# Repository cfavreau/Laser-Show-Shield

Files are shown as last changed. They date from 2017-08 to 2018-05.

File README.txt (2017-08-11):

Open Laser Show DAC
Arduino Laser Shield
By Christopher Favreau
cfavreau@fab-favreau.com
Last revised on August 17, 2011
Current Hardware Version: 3B
Project Web Sites:
http://www.fab-favreau.com/index.php/Main/OpenLaserShowDAC
https://github.com/cfavreau/Laser-Show-Shield

All included materials are copyright Christopher Favreau 2010 to 2017

This work is licensed under the Creative Commons Attribution 3.0 Unported License.

You are free to share and remix this work as long as you attribute the me the author
somewhere on/in your related work.

To view a copy of this license, visit http://creativecommons.org/licenses/by/3.0/

Description
--------------------------------------------------------------------------------

The Open Laser Show DAC is an Open Source Hardware/Software project.

It implements a Laser Show DAC (Digital to Analog Converter) that uses the ILDA standard laser projector
connector. The one exception that it uses singled ended color signals.

Specifications->
Scan Rates: 1 kpps to 30 kpps
XY Resolution:  12 Bits
Color Resolution:  3 bits (for a total of 512 colors)
Colors: Red, Green, Blue outputs
TTL Shutter Output
Built in test patterns accessible by button.

This board is built as an Arduino Shield.   It requires a Arduino 2009 (Duemilanove) or compatible Arduino
micro-controller board.   The important thing that is needed for compatibility is the FTDI USB to Serial
converter chip.  The newer UNO boards are not supported yet.   In order for the software/hardware to work
properly a jumper wire needs to be added between the CTS pin on the Arduino/FTDI chip and digital pin 8.  
This is used to control the stream of serial data being sent to the Arduino.  Some boards make this easy and
include a pad for the CTS pin (Arduino and Seeduino brands).   The Freeduino will work however it does not
break out a pad for the CTS pin (this makes it a bit more difficult to modify).

------------------------------------------------------------------------------------------------------------

Included in this project:

OLSDTest
--------------------------------------------------------------------------------
This program is written in Microsoft Visual C++ using MFC (Visual Studio 2005).
Use this program to test the OLSD hardware.  This software includes several built
in test patterns inlcuding the ILDA12k, ILDA30k, Quadrature, Laser Media, and a
few other test frames that I devised.

OLSD DLL
--------------------------------------------------------------------------------
This is a DLL library that uses the Open Laser Show Controller interface.   It can be used
by other applications to interface with the OLSD hardware in a standard way.   This DLL project
is written in Microsoft Visual C++ (using Visual Studio 2005).

The source code for the DLL test application is included as well.

OLSD Firmware
--------------------------------------------------------------------------------
This is the Arduino firmware.  It was tested using Arduino Duemilanove
with ATMega328 (http://www.arduino.cc/en/Main/ArduinoBoardDuemilanove)

It will fit in a smaller amount of flash however you may need to remove some
of the built in test frames.

This firmware supports point output rates up to 30kpps.  It also has
built in test patterns.  These are activated by pressed the button near the ILDA
connector.

OLSD Laser Shield Hardware
--------------------------------------------------------------------------------
Schematic, Board Layout, Gerbers, and Bill Of Materials (with Digi-Key stock numbers).
The schematic and board were done in the free version of Eagle CAD.  A PDF version
of the schematic has been included.  All parts except for PCB and Arduino can be
purchased from Digi-Key using the included Digi-Key part numbers.

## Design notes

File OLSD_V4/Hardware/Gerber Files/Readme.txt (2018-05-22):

Gerber Files produced by Eagle Lite V5.11
Using the CAM file:  http://www.sparkfun.com/tutorial/BeginningEmbedded/9-EaglePCBs/sfe-gerb274x.cam
Files are in the Gerber RS274X format

* Top and bottom copper (.GTL, .GBL)
* Top and bottom solder mask (.GTS, .GBS)
* Top and bottom silkscreen (.GTO, .GBO)
* Drill file, 2.4 leading (.TXT)

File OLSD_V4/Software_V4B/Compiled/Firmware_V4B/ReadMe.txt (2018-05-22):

Please edit the PROGRAM.BAT file to use the COM# that your Arduino is on.

To find out please go to the Ports in the Device Manager.

avrdude.exe -V -F -C avrdude.conf -p m328p -c stk500v1 -P COM6 -b 57600 -U flash:w:olsd.hex:a

The above line is set for COM6.   Your COM# may vary.  Replace the "6" with your own number.
Then run the PROGRAM.BAT file by double clicking on it.   This will program the Arduino with 
the new firmware.

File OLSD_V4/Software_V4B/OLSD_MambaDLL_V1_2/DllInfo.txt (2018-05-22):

Drivers are simply Windows DLLs. If you want to write your own driver, you will have to
implement and export the following functions (Delphi syntax):

=================================================================================================================
function MLRegisterDriver(b: PChar): word stdcall;

This function has to copy the characters MLDevice into the buffer b. This is to make sure the
DLL is a valid driver. The function can return a number, which will then be passed to as
parameter h in the functions below (in case the hardware driver supports multiple clients, and
has to keep track of them).

=================================================================================================================
function MLDevicePresent: boolean; stdcall;

This function should return true if the device is present (or if there is no way to determine it).

=================================================================================================================
function MLKind: word; stdcall;

Returns 1 for a frame oriented device, 2 for a point oriented device, 4 for an animation
oriented device. (For the different devices see MLDraw.) If the function is not present a frame
oriented device will be assumed.
Mamba calls these functions on program start, so it can list all output devices that are
available.
The following functions are used to do output to the device. The parameter h is the above
mentioned return value from MLRegisterDriver, c is the channel number (in case the
hardware can support multiple output channels, mamba always uses channel 0).

=================================================================================================================
function MLGetName(n: pchar): boolean; stdcall;

When called the driver should copy a name (20 chars max) to n

=================================================================================================================
function MLInitDevice(h: word): boolean; stdcall;

Called once when the driver is selected.

=================================================================================================================
function MLInitShow(h, c: word): boolean; stdcall;

Called immediately before output starts

=================================================================================================================
function MLDraw(h, c: word; d: PChar; n: integer): boolean; stdcall;

For a frame oriented device (Riya PCI Pro for example) this function is called for each frame.

D is a pointer to an array with n points
Point= packed record
   x,y,z: word;
   r,g,b: byte;
   reserved1, reserved2, reserved3: byte;
   intensity, reserved4, repeatpoint: byte;
end;

if repeatpoint is greater than 0 it should be displayed 1+repeatpoint times.

For a point oriented device (MediaLas PCI 12 for example) this function is called once for
each point (same data format).

For animation oriented devices (MediaLas HotBoard for example) there will be a call to
MLInitShow, followed by calls to MLDraw for each frame, after the show is through
MLHaltShow will be called, and the data can be sent to the device.

=================================================================================================================
function MLHaltShow(h, c: word): boolean; stdcall;

Called when output stops.

=================================================================================================================
function MLHalt: boolean; stdcall;

Called when the driver is unloaded

=================================================================================================================
function MLParams(h: word; c: word; p: PChar): boolean; stdcall;

p is a pointer to a Params structure
Params= packed record
size: word;
pointrate: longint;
invertblanking: boolean;
end;

size is the size in bytes of the complete structure (right now values of 6 or 7 are used, please
make sure you driver checks for this parameters). For a frame oriented driver this function is
used to set the scanrate in points per second. If invertblanking is set, the driver should invert
all intensity values (if possible). The driver should use safe default values.

=================================================================================================================
Using a driver with your own software

If you plan to use a MediaLas driver with your own software you should at least call the
following functions:

MLDevicePresent (on startup)
MLInitDevice (before first output)
MLInitShow (before output starts)
MLHaltShow (to end output)
MLHalt (before closing program)

It is highly recommended to call MLKind (if present) to check whether the device is point,
frame, or animation oriented.

When calling MLName please make sure the buffer you pass is at least 21 bytes long. When
calling MLParams, set the size parameter correctly.

A simple example driver and program (in Delphi) is available, please contact MediaLas
technical support.

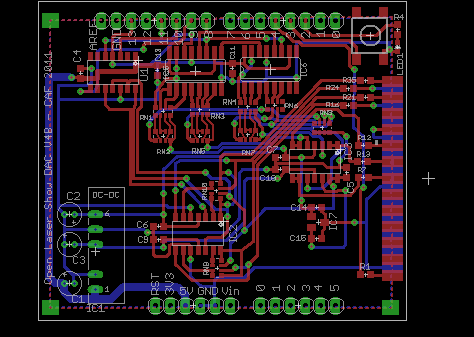
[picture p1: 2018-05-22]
OLSD_V4/Hardware/OLSD_V4B_Board.png

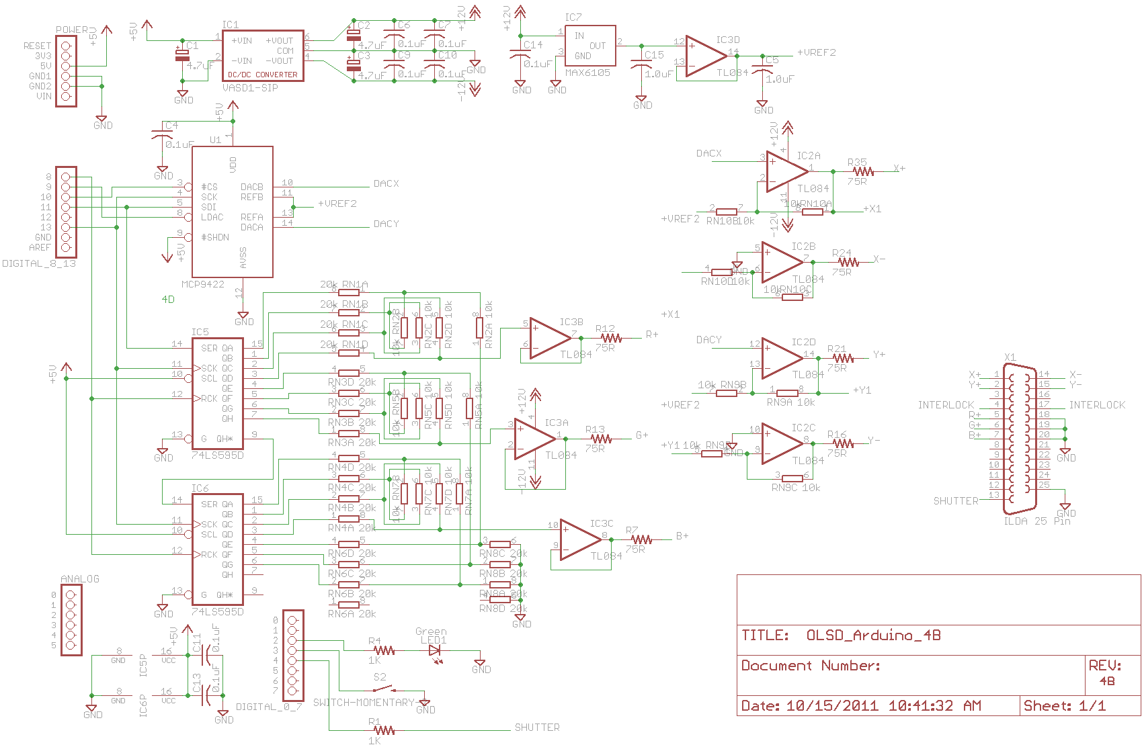
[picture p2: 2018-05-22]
OLSD_V4/Hardware/OLSD_V4B_Schematic.png

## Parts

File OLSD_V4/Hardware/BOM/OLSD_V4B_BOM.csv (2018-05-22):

Quantity | Name | Value | Digi-Key | Description | Parts | Cost Per Unit | Total Cost
2 | Resistor 0603 | 1K | P1.0KGCT-ND | 1k 1/10W 0603 Digikey 5% | R1, R4 | $0.02 | $0.04
7 | Resistor 0603 | 75R | P75GCT-ND | 75R 1/10W 0603 Digikey 5% | R7,R12,R13,R16,R21,R24,R35 | $0.02 | $0.14
2 | 10kx4 Resistor Array | CRA06E08310K0FTA | CRA6E810.0KACT-ND | RES ARRAY 10K OHM 4 RES 1206 1% (0603x4) | RN9, RN10 | $0.19 | $0.38
3 | 10kx4 Resistor Array | YC164-JR-0710KL | YC164J-10KTR-ND | RES ARRAY 10K OHM 8TRM 4 RES SMD 5%(0603 x 4) | RN2, RN5, RN7 | $0.04 | $0.12
5 | 20kx4 Resistor Array | YC164-JR-0720KL | YC164J-20KCT-ND | RES ARRAY 20K OHM 8TRM 4 RES SMD 5% (0603 x 4) | RN1, RN3, RN4, RN6, RN8 | $0.04 | $0.20
2 | 1.0 uF Capacitor 0603 | 1.0uF | 445-1327-1-ND | 1.0uF 16V 0603 package | C5, C15 | $0.17 | $0.34
3 | Capacitor Leaded | 4.7uF | ECE-A1EKA4R7 | 4.7 uF Electrolytic Capacitor 25V 20% | C1, C2, C3 | $0.23 | $0.69
8 | Capacitor 0603 | 0.1uF | 445-1326-1-ND | Bypass CAPs -> 0.1uF 16V 0603 package | C6, C7, C9, C10, C11, C13, C14, C15 | $0.07 | $0.56
1 | Male Header | 1x36 0.1" | WM6536-ND | Shield Header - 1 x 36 Male Header Gold Plated .24" mating length | U$1, U$2, U$3, U$4 | $1.50 | $1.50
1 | DB25 Female ILDA Conn | DB25 | L77SDB25S | CONN D-SUB RCPT 25POS GOLD FLASH | X1 | $1.41 | $1.41
1 | 12 Bit SPI DAC | MCP4922 | MCP4922T-E/SLCT-ND | 12 Bit Dual DAC Microchip - SPI - SOIC | U1 | $3.11 | $3.11
1 | SPST Push Button Switch | SPST | 450-1759-1-ND | SWITCH TACT MINI 6X6MM SMD | S2 | $0.24 | $0.24
2 | Quad Opamp | TL084CD | 497-3033-5-ND | Quad JFET OpAmp - SOIC Package | IC2, IC3 | $0.70 | $1.40
1 | 5V to +-12V DC to DC | RB-0512D | 945-1105-ND | CONV DC/DC 1W DL +/-12V OUT SIP | IC1 | $6.82 | $6.82
1 | Green LED 0603 |  | 475-2709-1-ND | LED SMARTLED GREEN 570NM 0603 @ 2mA = 2 mcd w/ 1.7V Forward Voltage | LED1 | $0.16 | $0.16
2 | 595 Shift Register | 74VHC595M | 74VHC595M-ND | IC REGISTER SHIFT 8BIT 16-SOIC | IC5, IC6 | $0.43 | $0.86
1 | 5.0V Voltage Reference | MAX6105EUR+T | MAX6105EUR+TCT-ND | Maxim 5V Precision Voltage Reference | IC7 | $0.78 | $0.78
Total Cost: |  | $18.75 |  |  | Total Cost: |  | $18.75
1 | 5V to +-12V DC to DC | VASD1-S5-D12-SIP | 102-1340-ND | CONVERTER DC/DC +/-12V OUT +5V IN 1W | IC1 | $5.58 | $5.58

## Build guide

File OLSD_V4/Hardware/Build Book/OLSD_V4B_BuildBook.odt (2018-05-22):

IC1 - 5V to +-12V DC to DC – 945-1105-ND – RB-0512D

Notes: None

C1, C2, C3 - 4.7 uF Electrolytic Capacitor 25V 20% – ECE-A1EKA4R7 – 4.7uF

Notes: Please pay attention to the polarity. All of the capacitors are not polarized in the same orientation on the board.

IC7 - 5.0V Voltage Reference – MAX6105EUR+TCT-ND – MAX6105EUR+T

Notes: None.

C5, C15 - 1.0 uF Capacitor 0603 – 445-1327-1-ND – 1.0 uF 0603

Notes: None.

LED1 - Green LED 0603 – 475-2709-1-ND

Notes: The orientation of the LED is important. Please orient the LED according to this drawing.

R1, R4 – 1k Resistor 0603 – P1.0KGCT-ND – 1k 0603

Notes: None.

S2 - SWITCH TACT MINI 6X6MM SMD – 450-1759-1-ND

Notes: None.

C6, C7, C9, C10, C11, C13, C14, C15- 0.1 uF Capacitor 0603 – 445-1326-1-ND – 0.1 uF 0603

Notes: None.

R7,R12,R13,R16,R21,R24,R35- 75R Resistor 0603 – P75GCT-ND

Notes: None.

RN9, RN10- RES ARRAY 10K OHM 4 RES 1206 1% (0603x4) – CRA6E810.0KACT-ND - CRA06E08310K0FTA

Notes: Please note that these are 1% resistor packs where as the ones used in the R2R color DACs are 5%. Do not mix them up.

RN2, RN5, RN7 - RES ARRAY 10K OHM 8TRM 4 RES SMD 5%(0603 x 4) – YC164J-10KTR-ND – YC164-JR-0710KL

Notes: None.

RN1, RN3, RN4, RN6, RN8 - RES ARRAY 20K OHM 8TRM 4 RES SMD 5% (0603 x 4) – YC164J-20KCT-ND - YC164-JR-0720KL

Notes: None.

U1 - 12 Bit Dual DAC Microchip - SPI - SOIC – MCP4922T-E/SLCT-ND – MCP4922

Notes: The dot on the board drawing represents pin 1 on the DAC.

IC5, IC6 - IC REGISTER SHIFT 8BIT 16-SOIC - 74VHC595M-ND – 74VHC595M

Notes: The dot on the board drawing represents pin 1 on the chip.

IC2, IC3 - Quad JFET OpAmp - SOIC Package – 497-3033-5-ND – TL084CD

Notes: The dot on the board drawing represents pin 1 on the chip. Pin 1 on the chip is represented by a flat edge and not by a dot.

U$1, U$2, U$3, U$4 - Shield Header - 1 x 36 Male Header Gold Plated .24" mating length – WM6536-ND

Notes: The single 36 pin header will have to be split into 2 x 8 sections and 2 x 6 sections. There will be a left over piece.

X1 – DB25 Female Solder Cup – L77SDB25S

Notes: The cups on the connector may have to be widened slightly using a screw driver or a scrap piece of circuit board. This connector is pressed on and then soldered. The top of the board is the top of the connector with pin 1.

OLSD V4B – Build Book – October 19, 2011

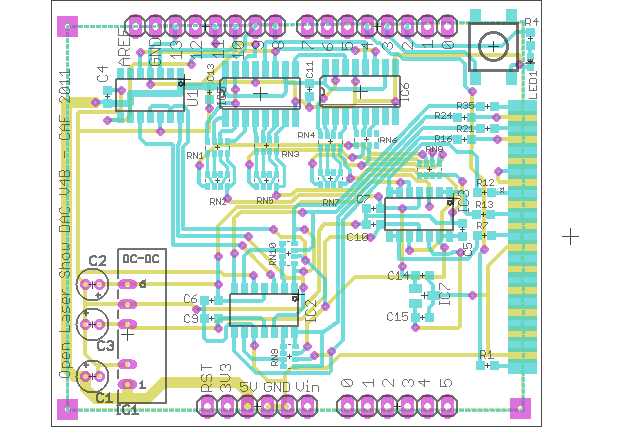
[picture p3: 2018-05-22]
OLSD_V4/Hardware/Build Book/OLSD_V4B_BoardBasePicture.png

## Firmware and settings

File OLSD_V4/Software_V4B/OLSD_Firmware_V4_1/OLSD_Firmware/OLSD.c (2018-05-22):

// Open Laser Show DAC V4B
// By Christopher Favreau
#warning PUT LICENSE HERE!!!
#include <avr/interrupt.h>
#include <avr/io.h>
#include "standard.h"
#include "usart.h"
#include "spi.h"
#include "timer.h"
#include "switch.h"
#include "test_frames.h"

// Port Map
// Jmp   Arduino Pin	AVR Pin		Direction	OLSD Func
//-----------------------------------------------------------------------------
// J1		Digital 0	PD0			Input		Serial RXD (on Arduino)
// J1		Digital 1	PD1			Output		Serial TXD (on Arduino)
// J1		Digital 2	PD2			Output		Status LED (1 == ON)
// J1		Digital 3	PD3(INT1)	Input		User Switch (0 == Pressed)
// J1		Digital 4	PD4			Output		ILDA Shutter
// J1		Digital 7	PD7			Output		#CTS (needs jumper #CTS->FTDI)
// J2		Digital	8	PB0			Output		Latch Color Regs (1 == Latch)
// J2		Digital 9	PB1			Output		#LDAC on uChip DAC
// J2		Digital 10	PB2(SS)		Output		#CS on uChip DAC
// J2		Digital 11	PB3(MOSI)	Output		MOSI (SPI Data Out)
// J2		Digital 13	PB5(SCK)	Output		SCK (SPI Serial Clock)

// Store the Identifier in FLASH
unsigned char OLSD_IDENTIFIER_STRING[] PROGMEM = "OLSD4.1.0\0";

// Status LED Variables
unsigned int status_counter = 0;

// Output Variables
BYTE command = 0;
BYTE x = 0;
BYTE y = 0;
BYTE red = 0;
BYTE green = 0;
BYTE blue = 0;
BYTE fifthbits = 0;

// Laser Packet
BYTE dcommand = 0;
BYTE dx = 0;
BYTE dy = 0;
BYTE dxy = 0;
BYTE drg = 0;
BYTE dbi = 0;

WORD spi_word = 0;

// Pointer to the reset vector for the firmware
void (*reset)( void ) = 0x0000;
void blank_and_center(void);

// ----------------------------------------------------------------------

BOOL output_monochrome_pattern = FALSE;
BOOL output_swap_xy = FALSE;

void output_pattern(BYTE *pStream, unsigned int length)
{
	unsigned int i = 0;

	while (i < length)
	{
		// Read a command
		command = pgm_read_byte(&pStream[i++]);

		// This being a test frame
		// We should... have a point output command
		if ((command != 0x20) && (command != 0x21))
		{
			// hmmm... we had some other command
			// Just get the next byte in the streams
			continue;
		}

		// Read the X and Y coordinates from the stream
		dx = pgm_read_byte(&pStream[i++]);
		dy = pgm_read_byte(&pStream[i++]);
		dxy = pgm_read_byte(&pStream[i++]);
		
		// Check to see if the colors stay the same
		// If they do stay the same then don't load the color bytes
		if (command != 0x21)
		{
			// Read the color bytes
			drg = pgm_read_byte(&pStream[i++]);
			dbi = pgm_read_byte(&pStream[i++]);
		}
		
		// Output our point
		// Now output the actual point
		
		// Decode into 4 bit RGBI
		red = (drg >> 4);
		green = (drg & 0x0F);
		blue = (dbi >> 4);
		
		// Check the monochrome flag
		if (output_monochrome_pattern)
		{
			// Make all the colors the same brightness
			register unsigned char color = red;
			if (green > color) color = green;
			if (blue > color) color = blue;
			red = color;
			green = color;
			blue = color;
		}

		// Do the fifth bit for the color
		fifthbits = 0;
		if (red) fifthbits |= 0x10;
		if (green) fifthbits |= 0x20;
		if (blue) fifthbits |= 0x40;

		// Check to see if it is time to output a point yet?
		while (!output_flag) asm("nop");
		// Reset our output flag/counter
		output_flag = 0;

		// Pull up the latch lines on the DAC and colors before we
		// go and send more data down the SPI bus
		// LDAC
		portb.bit1 = 1;
		// Color Latches
		portb.bit0 = 0;

		// Load DAC A
		// X X X PowerMode Load Output AddrB AddrA 
		// pull down chip select!
		if (!output_swap_xy)
			spi_word = 0b0111000000000000 | (dy << 4) | ((dxy & 0xF0) >> 4);
		else
			spi_word = 0b0111000000000000 |(dx << 4) | (dxy & 0x0F);
		portb.bit2 = 0;
		SPDR = spi_word >> 8;
		while (!(SPSR & (1 << SPIF)));
		SPDR = spi_word & 0x00FF;
		while (!(SPSR & (1 << SPIF)));
		// pull up chip select!
		portb.bit2 = 1;
		asm("nop");
		
		// NOP NOP NOP NOP!??? how many?
		// Load DAC B and update the output (assign a 0 to output)
		// pull down chip select!
		if (!output_swap_xy)
			spi_word = 0b1111000000000000 | (dx << 4) | (dxy & 0x0F);
		else
			spi_word = 0b1111000000000000 | (dy << 4) | ((dxy & 0xF0) >> 4);
		portb.bit2 = 0;
		SPDR = spi_word >> 8;
		while (!(SPSR & (1 << SPIF)));
		SPDR = spi_word & 0x00FF;
		while (!(SPSR & (1 << SPIF)));
		// Pull up chip select!
		portb.bit2 = 1;

		// Colors
		// *** REMEMBER that a shift register passes the 1st 8 bits
		// on to the 2nd shift register so we do the BLUE first!
		// B goes first
		SPDR = fifthbits | blue;
		while (!(SPSR & (1 << SPIF)));
		
		// RG go second
		SPDR = (green << 4) | red;
		while (!(SPSR & (1 << SPIF)));
		
		// Now latch the Colors and the DAC
		portb.bit0 = 1;

		// Pull the LDAC line LOW to load the DAC's values
		portb.bit1 = 0;

		// and set the shutter to OFF since it might be ON
		portd.bit4 = 0;

		// Do the Status LED
		status_counter++;
		if (status_counter < 500)
		{
			// Reset the LED to flip
			portd.bit2 = 1;
		}
		else
		{
			portd.bit2 = 0;
		}
		if (status_counter > 1000) status_counter = 0;
	}
}

void output_test_pattern(void)
{
	// Clear the button press
	switch_pressed = 0;

	// Reset the output monochrome flag
	output_monochrome_pattern = FALSE;

	// The first button press starts the ILDA 12k Test Pattern
	// Then:  Square Wave, Laser Media, New Test Pattern
	// This Round: 12 kpps
	// Next Round: 30 kpps

	while (1)
	{
		switch ((switch_pressed % 13) + 1)
		{
		case (1):
			set_timer_pps(12000);
			output_pattern(ILDA12K_IMAGE, ILDA12K_POINT_COUNT);
			break;
		case (2):
			set_timer_pps(12000);
			output_pattern(SQUARE_IMAGE, SQUARE_POINT_COUNT);
			break;
		case (3):
			set_timer_pps(12000);
			output_pattern(LASERMEDIA_IMAGE, LASERMEDIA_POINT_COUNT);
			break;
		case (4):
			set_timer_pps(12000);
			output_pattern(NEWTEST_IMAGE, NEWTEST_POINT_COUNT);
			break;
		case (5):
			set_timer_pps(12000);
			output_swap_xy = TRUE;
			output_pattern(NEWTEST_IMAGE, NEWTEST_POINT_COUNT);
			output_swap_xy = FALSE;
			break;
		case (6):
			blank_and_center();
			// We are already blanked... just wait for the switch
			wait_for_switch();
			break;
		case (7):
			set_timer_pps(30000);
			output_pattern(ILDA12K_IMAGE, ILDA12K_POINT_COUNT);
			break;
		case (8):
			set_timer_pps(30000);
			output_pattern(SQUARE_IMAGE, SQUARE_POINT_COUNT);
			break;
		case (9):
			set_timer_pps(30000);
			output_pattern(LASERMEDIA_IMAGE, LASERMEDIA_POINT_COUNT);
			break;
		case (10):
			set_timer_pps(30000);
			output_pattern(NEWTEST_IMAGE, NEWTEST_POINT_COUNT);
			break;
		case (11):
			set_timer_pps(30000);
			output_swap_xy = TRUE;
			output_pattern(NEWTEST_IMAGE, NEWTEST_POINT_COUNT);
			output_swap_xy = FALSE;
			break;
		case (12):
			blank_and_center();
			// Toggle the monochrome flag
			output_monochrome_pattern = !output_monochrome_pattern;
			// It is important to block so we don't toggle this flag
			// randomly ... wait for the switch again
			wait_for_switch();
			break;
		}
	}
}

inline void PrintIdentifier(void)
{
	// Get the OLSD Identifier from Flash instead of RAM
	// so we don't use up valuable RAM
	unsigned char i = 0;
	unsigned char byte = pgm_read_byte(&OLSD_IDENTIFIER_STRING[i]);
	// Loop until we run into the NULL terminator
	while (byte)
	{
		USART_Write(byte);
		byte = pgm_read_byte(&OLSD_IDENTIFIER_STRING[i++]);
	}
}

void blank_and_center(void)
{
	// Define a center
	#define CENTER_X 2047
	#define CENTER_Y 2047

	// Pull up the latch lines on the DAC and colors before we
	// go and send more data down the SPI bus
	// LDAC
	portb.bit1 = 1;
	// Color Latches
	portb.bit0 = 0;

	// Load DAC A
	// X X X PowerMode Load Output AddrB AddrA 
	// pull down chip select!
	spi_word = 0b0111000000000000 | CENTER_X;
	portb.bit2 = 0;
	SPDR = spi_word >> 8;
	while (!(SPSR & (1 << SPIF)));
	SPDR = spi_word & 0x00FF;
	while (!(SPSR & (1 << SPIF)));
	// pull up chip select!
	portb.bit2 = 1;
	asm("nop");
	
	// NOP NOP NOP NOP!??? how many?
	// Load DAC B and update the output (assign a 0 to output)
	// pull down chip select!
	spi_word = 0b1111000000000000 | CENTER_Y;
	portb.bit2 = 0;
	SPDR = spi_word >> 8;
	while (!(SPSR & (1 << SPIF)));
	SPDR = spi_word & 0x00FF;
	while (!(SPSR & (1 << SPIF)));
	// Pull up chip select!
	portb.bit2 = 1;

	// Colors
	// RG go first
	SPDR = 0;
	while (!(SPSR & (1 << SPIF)));
	
	// B (and the 5th bits) go next
	SPDR = 0;
	while (!(SPSR & (1 << SPIF)));
	
	// Now latch the Colors and the DAC
	portb.bit0 = 1;

	// Pull the LDAC line LOW to load the DAC's values
	portb.bit1 = 0;

	// and set the shutter to closed!!!
	portd.bit4 = 1;

	// Wait a few cycles before setting the latch lines up again
	asm("nop");
	asm("nop");
	asm("nop");
	asm("nop");

	// Pull up the latch lines on the DAC and colors before we
	// go and send more data down the SPI bus
	// LDAC
	portb.bit1 = 1;
	// Color Latches
	portb.bit0 = 0;
}

// DEBUG
unsigned char cx = 0;
unsigned char cy = 0;

int main(void)
{
	// Initialize our IO Ports
	
	// Port D - Serial + Status LED + User Switch + Shutter + CTS
	DDRD = 0b10010100;
	//PORTD = 0b00000011;
	// Pull up the user switch line
	ddrd.bit3 = 0;
	portd.bit3 = 1;

	/*
	// Test LED and Switch CODE
	while (1)
	{
		portd.bit2 = !pind.bit3;
	}
	*/

	// Initialize our SPI port to output to our DAC
	ddrb.bit2 = 1;
	portb.bit2 = 1;
	SPI_Init();

	// LDAC - disable
	ddrb.bit1 = 1;
	portb.bit1 = 1;

	// CTS Pin
	ddrb.bit0 = 1;
	portb.bit0 = 0;

	// Status LED
	ddrc.bit4 = 1;
	// Turn the LED ON
	portd.bit2 = 1;

	// Initialize our USART at 2 Mbps
	USART_Init();

	// Initialize the output point timer
	init_timer();

	// Blank and center
	blank_and_center();

	// Initialize the button input device
	init_switch();

	// Turn on interrupts
	sei();

	// Print Boot Message
	PrintIdentifier();

	CTS_ON;

	// DEBUG
	//output_test_pattern();
	//while (1) output_pattern(NEWTEST_IMAGE, NEWTEST_POINT_COUNT);

	// Loop forever
	while (1)
	{
		// Tell the USB chip we want to start getting data over our serial port
		CTS_ON;

		// DEBUG
		//switch_pressed = 1;
		
		// Read the command byte from the packet
		//READ(command);
		while (!(UCSR0A & (1 << RXC0)) && (switch_pressed == 0)); dcommand = UDR0;
		//while (!(UCSR0A & (1 << RXC0))); dcommand = UDR0;
		//READ(dcommand);

		///*
		// Before we read a command packet
		// We need to check to see if the button was pressed.
		// If the button was pressed then go into the Test Output Routine
		if (switch_pressed > 0)
		{
			// Jump to the test pattern routine
			output_test_pattern();
			// If we ever return...
			// Rejoin the loop after we are done with the test pattern
			continue;
		}
		//*/

		// Extract the command from the dcommand byte
		command = dcommand & 0xF0;

		// Check to see if we have a point output command
		// Command 0x20 -> Output Point
		if (command != 0x20)
		{
			// Check to see if it is a synchronization command
			if (command == 0xFF) continue;
			
			// Read the rest of the packet
			READ(dx);
			READ(dy);
			READ(dxy);
			READ(drg);

			// Check to see if it is a point output rate command
			if (command == 0x10)
			{
				// Set the point output rate
				// dx is the upper byte and dy is the lower byte
				// of the 16 bit unsigned pps rate
				set_timer_pps((dx << 8) + dy);
			}
			else
			// Check to see if it is a Reset command
			if (command == 0xF0)
			{
				// Reset the Firmware
				reset();
			}
			else
			// Check to see if it is Identify command
			if (command == 0xE0)
			{
				// Send the identifier string
				PrintIdentifier();
			}
			else
			{
				// What was that
				USART_Write('?');
			}

			// We aren't going to output a point
			continue;
		}

		// Command 0x20 - point output
		// Read the XY and colors
		READ(dx);
		READ(dy);
		READ(dxy);
		READ(drg);
		
		// Tell the USB chip we want to STOP getting data over our serial port
		CTS_OFF;
		
		// Output our point
		
		// Decode into 4 bit RGBI
		red = (drg >> 4);
		green = (drg & 0x0F);
		blue = (dcommand & 0x0F);
		
		// Fifth bits are the UPPER Nibble
		fifthbits = 0;
		if (red) fifthbits |= 0x10;
		if (green) fifthbits |= 0x20;
		if (blue) fifthbits |= 0x40;

		// Check to see if it is time to output a point yet?
		while (!output_flag) asm("nop");
		// Reset our output flag/counter
		output_flag = 0;

		// Pull up the latch lines on the DAC and colors before we
		// go and send more data down the SPI bus
		// LDAC
		portb.bit1 = 1;
		// Color Latches
		portb.bit0 = 0;

		// Load DAC A
		// X X X PowerMode Load Output AddrB AddrA 
		// pull down chip select!
		spi_word = 0b0111000000000000 | (dy << 4) | ((dxy & 0xF0) >> 4);
		portb.bit2 = 0;
		SPDR = spi_word >> 8;
		while (!(SPSR & (1 << SPIF)));
		SPDR = spi_word & 0x00FF;
		while (!(SPSR & (1 << SPIF)));
		// pull up chip select!
		portb.bit2 = 1;
		asm("nop");
		
		// NOP NOP NOP NOP!??? how many?
		// Load DAC B and update the output (assign a 0 to output)
		// pull down chip select!
		spi_word = 0b1111000000000000 | (dx << 4) | (dxy & 0x0F);
		portb.bit2 = 0;
		SPDR = spi_word >> 8;
		while (!(SPSR & (1 << SPIF)));
		SPDR = spi_word & 0x00FF;
		while (!(SPSR & (1 << SPIF)));
		// Pull up chip select!
		portb.bit2 = 1;

		// Colors
		// *** REMEMBER that a shift register passes the 1st 8 bits
		// on to the 2nd shift register so we do the BLUE first!
		// B goes first
		SPDR = fifthbits | blue;
		while (!(SPSR & (1 << SPIF)));

		// RG go second
		SPDR = (green << 4) | red;
		while (!(SPSR & (1 << SPIF)));
		
		// Now latch the Colors and the DAC
		portb.bit0 = 1;

		// Pull the LDAC line LOW to load the DAC's values
		portb.bit1 = 0;

		// and set the shutter to OFF since it might be ON
		portd.bit4 = 0;

		// Do the Status LED
		status_counter++;
		if (status_counter < 500)
		{
			// Reset the LED to flip
			portd.bit2 = 1;
		}
		else
		{
			portd.bit2 = 0;
		}
		if (status_counter > 1000) status_counter = 0;
	}

	return 1;
}

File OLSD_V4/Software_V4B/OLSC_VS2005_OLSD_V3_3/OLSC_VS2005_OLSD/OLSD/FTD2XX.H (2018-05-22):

/*++

Copyright (c) 2001-2004  Future Technology Devices International Ltd.

Module Name:

    ftd2xx.h

Abstract:

    Native USB device driver for FTDI FT8U232/245
    FTD2XX library definitions

Environment:

    kernel & user mode

Revision History:

    13/03/01    awm     Created.
	13/01/03	awm		Added device information support.
	19/03/03	awm		Added FT_W32_CancelIo.
	12/06/03	awm		Added FT_StopInTask and FT_RestartInTask.
	18/09/03	awm		Added FT_SetResetPipeRetryCount.
	10/10/03	awm		Added FT_ResetPort.
	23/01/04	awm		Added support for open-by-location.
	16/03/04	awm		Added support for FT2232C.
	23/09/04	awm		Added support for FT232R.

	
--*/

#include <windows.h>

#ifndef FTD2XX_H
#define FTD2XX_H

// The following ifdef block is the standard way of creating macros
// which make exporting from a DLL simpler.  All files within this DLL
// are compiled with the FTD2XX_EXPORTS symbol defined on the command line.
// This symbol should not be defined on any project that uses this DLL.
// This way any other project whose source files include this file see
// FTD2XX_API functions as being imported from a DLL, whereas this DLL
// sees symbols defined with this macro as being exported.

#ifdef FTD2XX_EXPORTS
#define FTD2XX_API __declspec(dllexport)
#else
#define FTD2XX_API __declspec(dllimport)
#endif


typedef PVOID	FT_HANDLE;
typedef ULONG	FT_STATUS;

//
// Device status
//
enum {
    FT_OK,
    FT_INVALID_HANDLE,
    FT_DEVICE_NOT_FOUND,
    FT_DEVICE_NOT_OPENED,
    FT_IO_ERROR,
    FT_INSUFFICIENT_RESOURCES,
    FT_INVALID_PARAMETER,
    FT_INVALID_BAUD_RATE,

    FT_DEVICE_NOT_OPENED_FOR_ERASE,
    FT_DEVICE_NOT_OPENED_FOR_WRITE,
    FT_FAILED_TO_WRITE_DEVICE,
    FT_EEPROM_READ_FAILED,
    FT_EEPROM_WRITE_FAILED,
    FT_EEPROM_ERASE_FAILED,
	FT_EEPROM_NOT_PRESENT,
	FT_EEPROM_NOT_PROGRAMMED,
	FT_INVALID_ARGS,
	FT_NOT_SUPPORTED,
	FT_OTHER_ERROR
};


#define FT_SUCCESS(status) ((status) == FT_OK)

//
// FT_OpenEx Flags
//

#define FT_OPEN_BY_SERIAL_NUMBER    1
#define FT_OPEN_BY_DESCRIPTION      2
#define FT_OPEN_BY_LOCATION			4

//
// FT_ListDevices Flags (used in conjunction with FT_OpenEx Flags
//

#define FT_LIST_NUMBER_ONLY			0x80000000
#define FT_LIST_BY_INDEX			0x40000000
#define FT_LIST_ALL					0x20000000

#define FT_LIST_MASK (FT_LIST_NUMBER_ONLY|FT_LIST_BY_INDEX|FT_LIST_ALL)

//
// Baud Rates
//

#define FT_BAUD_300			300
#define FT_BAUD_600			600
#define FT_BAUD_1200		1200
#define FT_BAUD_2400		2400
#define FT_BAUD_4800		4800
#define FT_BAUD_9600		9600
#define FT_BAUD_14400		14400
#define FT_BAUD_19200		19200
#define FT_BAUD_38400		38400
#define FT_BAUD_57600		57600
#define FT_BAUD_115200		115200
#define FT_BAUD_230400		230400
#define FT_BAUD_460800		460800
#define FT_BAUD_921600		921600

//
// Word Lengths
//

#define FT_BITS_8			(UCHAR) 8
#define FT_BITS_7			(UCHAR) 7
#define FT_BITS_6			(UCHAR) 6
#define FT_BITS_5			(UCHAR) 5

//
// Stop Bits
//

#define FT_STOP_BITS_1		(UCHAR) 0
#define FT_STOP_BITS_1_5	(UCHAR) 1
#define FT_STOP_BITS_2		(UCHAR) 2

//
// Parity
//

#define FT_PARITY_NONE		(UCHAR) 0
#define FT_PARITY_ODD		(UCHAR) 1
#define FT_PARITY_EVEN		(UCHAR) 2
#define FT_PARITY_MARK		(UCHAR) 3
#define FT_PARITY_SPACE		(UCHAR) 4

//
// Flow Control
//

#define FT_FLOW_NONE        0x0000
#define FT_FLOW_RTS_CTS     0x0100
#define FT_FLOW_DTR_DSR     0x0200
#define FT_FLOW_XON_XOFF    0x0400

//
// Purge rx and tx buffers
//
#define FT_PURGE_RX         1
#define FT_PURGE_TX         2

//
// Events
//

typedef void (*PFT_EVENT_HANDLER)(DWORD,DWORD);

#define FT_EVENT_RXCHAR		    1
#define FT_EVENT_MODEM_STATUS   2

//
// Timeouts
//

#define FT_DEFAULT_RX_TIMEOUT   300
#define FT_DEFAULT_TX_TIMEOUT   300

//
// Device types
//

typedef ULONG	FT_DEVICE;

enum {
    FT_DEVICE_BM,
    FT_DEVICE_AM,
    FT_DEVICE_100AX,
    FT_DEVICE_UNKNOWN,
    FT_DEVICE_2232C,
    FT_DEVICE_232R
};


#ifdef __cplusplus
extern "C" {
#endif


FTD2XX_API
FT_STATUS WINAPI FT_Open(
	int deviceNumber,
	FT_HANDLE *pHandle
	);

FTD2XX_API
FT_STATUS WINAPI FT_OpenEx(
    PVOID pArg1,
    DWORD Flags,
    FT_HANDLE *pHandle
    );

FTD2XX_API 
FT_STATUS WINAPI FT_ListDevices(
	PVOID pArg1,
	PVOID pArg2,
	DWORD Flags
	);

FTD2XX_API
FT_STATUS WINAPI FT_Close(
    FT_HANDLE ftHandle
    );

FTD2XX_API
FT_STATUS WINAPI FT_Read(
    FT_HANDLE ftHandle,
    LPVOID lpBuffer,
    DWORD nBufferSize,
    LPDWORD lpBytesReturned
    );

FTD2XX_API 
FT_STATUS WINAPI FT_Write(
    FT_HANDLE ftHandle,
    LPVOID lpBuffer,
    DWORD nBufferSize,
    LPDWORD lpBytesWritten
    );

FTD2XX_API 
FT_STATUS WINAPI FT_IoCtl(
    FT_HANDLE ftHandle,
    DWORD dwIoControlCode,
    LPVOID lpInBuf,
    DWORD nInBufSize,
    LPVOID lpOutBuf,
    DWORD nOutBufSize,
    LPDWORD lpBytesReturned,
    LPOVERLAPPED lpOverlapped
    );

FTD2XX_API
FT_STATUS WINAPI FT_SetBaudRate(
    FT_HANDLE ftHandle,
	ULONG BaudRate
	);

FTD2XX_API
FT_STATUS WINAPI FT_SetDivisor(
    FT_HANDLE ftHandle,
	USHORT Divisor
	);

FTD2XX_API
FT_STATUS WINAPI FT_SetDataCharacteristics(
    FT_HANDLE ftHandle,
	UCHAR WordLength,
	UCHAR StopBits,
	UCHAR Parity
	);

FTD2XX_API
FT_STATUS WINAPI FT_SetFlowControl(
    FT_HANDLE ftHandle,
    USHORT FlowControl,
    UCHAR XonChar,
    UCHAR XoffChar
	);

FTD2XX_API
FT_STATUS WINAPI FT_ResetDevice(
    FT_HANDLE ftHandle
	);

FTD2XX_API
FT_STATUS WINAPI FT_SetDtr(
    FT_HANDLE ftHandle
	);

FTD2XX_API
FT_STATUS WINAPI FT_ClrDtr(
    FT_HANDLE ftHandle
	);

FTD2XX_API
FT_STATUS WINAPI FT_SetRts(
    FT_HANDLE ftHandle
	);

FTD2XX_API
FT_STATUS WINAPI FT_ClrRts(
    FT_HANDLE ftHandle
	);

FTD2XX_API
FT_STATUS WINAPI FT_GetModemStatus(
    FT_HANDLE ftHandle,
	ULONG *pModemStatus
	);

FTD2XX_API
FT_STATUS WINAPI FT_SetChars(
    FT_HANDLE ftHandle,
	UCHAR EventChar,
	UCHAR EventCharEnabled,
	UCHAR ErrorChar,
	UCHAR ErrorCharEnabled
    );

FTD2XX_API
FT_STATUS WINAPI FT_Purge(
    FT_HANDLE ftHandle,
	ULONG Mask
	);

FTD2XX_API
FT_STATUS WINAPI FT_SetTimeouts(
    FT_HANDLE ftHandle,
	ULONG ReadTimeout,
	ULONG WriteTimeout
	);

FTD2XX_API
FT_STATUS WINAPI FT_GetQueueStatus(
    FT_HANDLE ftHandle,
	DWORD *dwRxBytes
	);

FTD2XX_API
FT_STATUS WINAPI FT_SetEventNotification(
    FT_HANDLE ftHandle,
	DWORD Mask,
	PVOID Param
	);

FTD2XX_API
FT_STATUS WINAPI FT_GetStatus(
    FT_HANDLE ftHandle,
    DWORD *dwRxBytes,
    DWORD *dwTxBytes,
    DWORD *dwEventDWord
	);

FTD2XX_API
FT_STATUS WINAPI FT_SetBreakOn(
    FT_HANDLE ftHandle
    );

FTD2XX_API
FT_STATUS WINAPI FT_SetBreakOff(
    FT_HANDLE ftHandle
    );

FTD2XX_API
FT_STATUS WINAPI FT_SetWaitMask(
    FT_HANDLE ftHandle,
    DWORD Mask
    );

FTD2XX_API
FT_STATUS WINAPI FT_WaitOnMask(
    FT_HANDLE ftHandle,
    DWORD *Mask
    );

FTD2XX_API
FT_STATUS WINAPI FT_GetEventStatus(
    FT_HANDLE ftHandle,
    DWORD *dwEventDWord
    );

FTD2XX_API
FT_STATUS WINAPI FT_ReadEE(
    FT_HANDLE ftHandle,
	DWORD dwWordOffset,
    LPWORD lpwValue
	);
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
